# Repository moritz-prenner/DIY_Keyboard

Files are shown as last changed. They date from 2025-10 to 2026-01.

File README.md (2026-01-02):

# DIY_Keyboard 

This project is a full size Keyboard powered by a rp2040 pro micro and a custom pcb designed by myself :)
After I am going to build it it should (hopefully) function like a regular storebought keyboard. It even contains a knob to control volume for example.
I built this project to get better at pcb design and learn something new about keyboard firmware.

Note for the reviewer:

As you probably already seen, my total (in the bom) is around 95$. But this number is without the filament cost for the printing of the case. 
Even tho I am probably going to spend my tickets I am going to earn with this project on filament, I still estimated the cost and added it to the bom total.
That makes my funding request (around 120 - 130 $) - of course I am going to return the rest if it is cheaper than expected.


image (1)
image (2)


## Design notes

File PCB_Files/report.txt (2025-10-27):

Warning: Width correction constrained.  The width correction value must be in the range of [0.000001 mm; 0.199999 mm] for the current design rules.
Plotted to 'D:\DIY_Keyboard\DIY_Keyboard-F_Cu.pdf'.
Plotted to 'D:\DIY_Keyboard\DIY_Keyboard-B_Cu.pdf'.
Plotted to 'D:\DIY_Keyboard\DIY_Keyboard-F_Paste.pdf'.
Plotted to 'D:\DIY_Keyboard\DIY_Keyboard-B_Paste.pdf'.
Plotted to 'D:\DIY_Keyboard\DIY_Keyboard-F_Silkscreen.pdf'.
Plotted to 'D:\DIY_Keyboard\DIY_Keyboard-B_Silkscreen.pdf'.
Plotted to 'D:\DIY_Keyboard\DIY_Keyboard-F_Mask.pdf'.
Plotted to 'D:\DIY_Keyboard\DIY_Keyboard-B_Mask.pdf'.
Plotted to 'D:\DIY_Keyboard\DIY_Keyboard-Edge_Cuts.pdf'.
Info: Done.
Info: Done.

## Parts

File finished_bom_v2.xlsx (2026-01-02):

BOM DIY Keyboard
number | name | price | shipping | customs | total | store | link | payed by
1 | pcb | $24.70 | $18.69 | $8.68 | $52.07 | JLCPCB | https://jlcpcb.com/ | Hackclub
2 | case part 1 | printing legion* |  |  |  |  |  | Hackclub
3 | case part 2 | printing legion* |  |  |  |  |  | Hackclub
4 | oled screen | $0.00 | $0.00 | $0.00 | $0.00 | none | none | myself
5 | microcontroller | $4.12 | $0.00 | - | $4.12 | Alieexpress | link (https://www.aliexpress.us/item/3256806413079215.html) | Hackclub
6 | switches | $14.40 | $0.00 | - | $14.40 | Alieexpress | link (https://www.aliexpress.us/item/3256807287812473.html?curPageLogUid=IzEzjf9NA2AT) | Hackclub
7 | screws | $12.32 | $0.00 | - | $12.32 | Alieexpress | link (https://www.aliexpress.us/item/3256807092650644.html?curPageLogUid=jpGcRnpkoJSX) | Hackclub
8 | threaded inserts | $4.19 | $0.00 | - | $4.19 | Alieexpress | link (https://www.aliexpress.us/item/3256803951626702.html?curPageLogUid=LZ68UpslQYpl) | Hackclub
9 | diodes | $2.97 | - | - | $2.97 | Alieexpress | link (https://www.aliexpress.us/item/3256806974248533.html?curPageLogUid=eBpdBSmcdIFc) | Hackclub
10 | rotary encoder | $1.52 | - | - | $1.52 | Alieexpress | link (https://www.aliexpress.us/item/3256807457768762.html?curPageLogUid=V7HCYoGuFoAu) | Hackclub
11 | keycaps | $4.88 | - | - | $4.88 | Alieexpress | link (https://www.aliexpress.us/item/3256809711493049.html) | Hackclub
12 | tweezers | $1.52 | $0.00 | - | $1.52 | Alieexpress | link (https://www.aliexpress.us/item/2255800812589859.html?curPageLogUid=6AeCtISjiv0Y) | Hackclub
 |  |  |  | total | $97.99
 | * Disclaimer:
 | Because I am planning to participate in construct
 | I am probably going to print the parts myself.
 | I am not going to count my work for the keyboard case for construct!!!

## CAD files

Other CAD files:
CAD_Files/Keyboard_case_lower_part.dwg
CAD_Files/Keyboard_case_upper_part.dwg

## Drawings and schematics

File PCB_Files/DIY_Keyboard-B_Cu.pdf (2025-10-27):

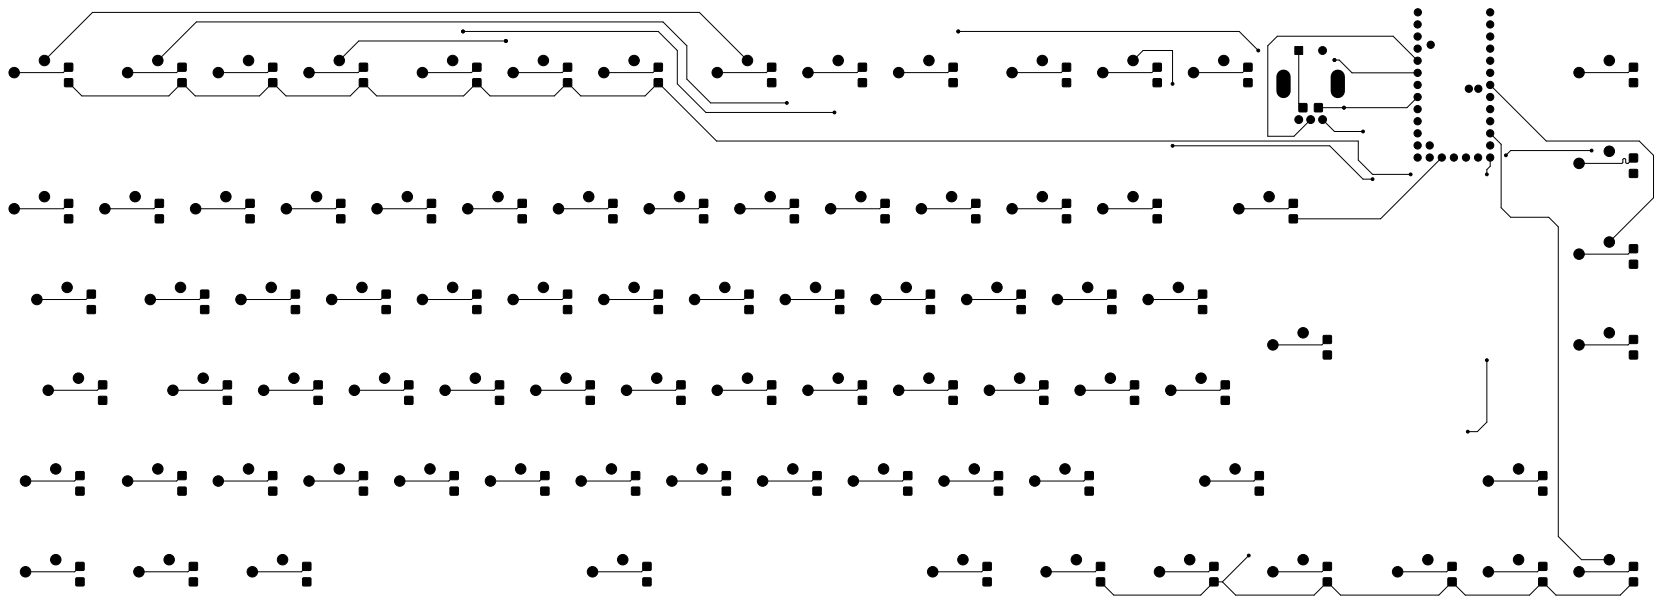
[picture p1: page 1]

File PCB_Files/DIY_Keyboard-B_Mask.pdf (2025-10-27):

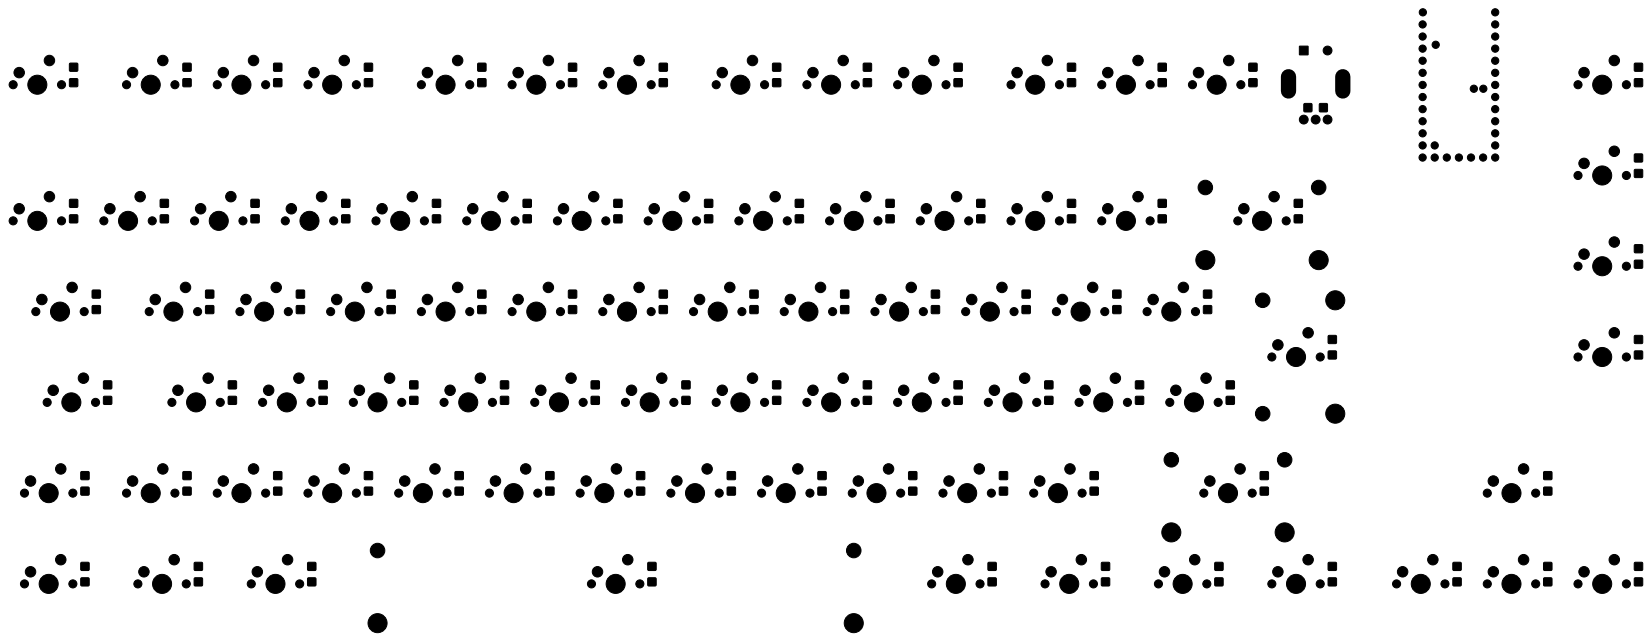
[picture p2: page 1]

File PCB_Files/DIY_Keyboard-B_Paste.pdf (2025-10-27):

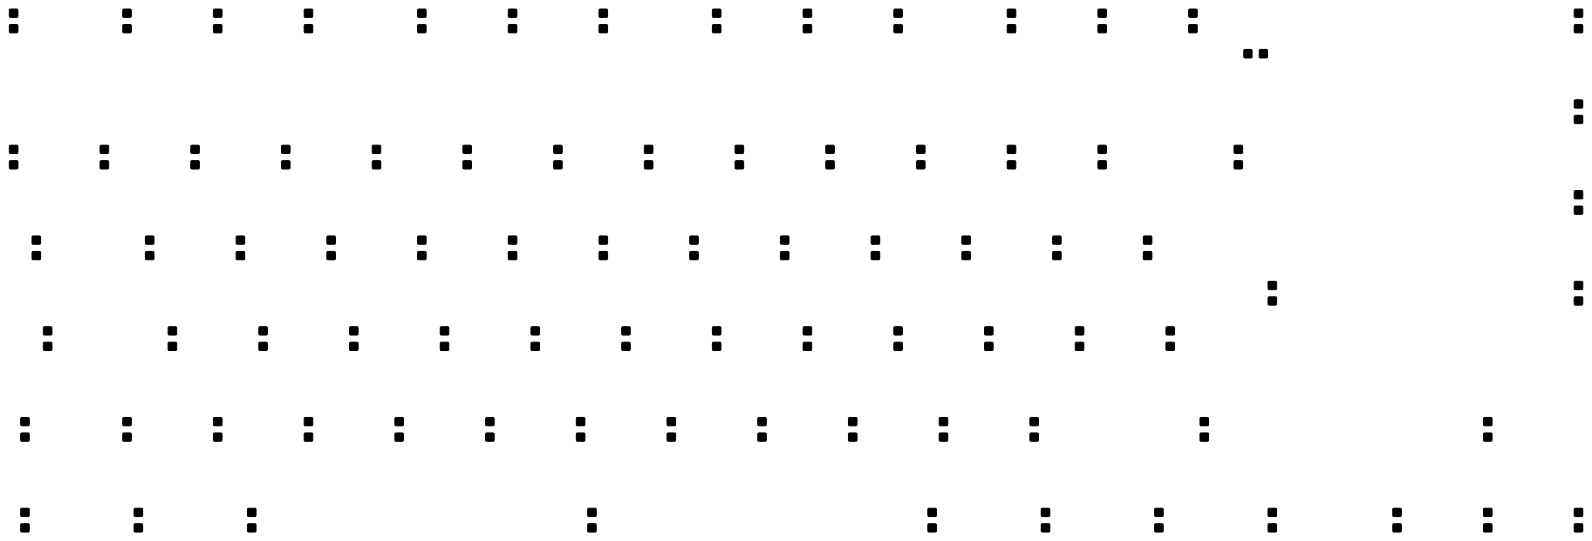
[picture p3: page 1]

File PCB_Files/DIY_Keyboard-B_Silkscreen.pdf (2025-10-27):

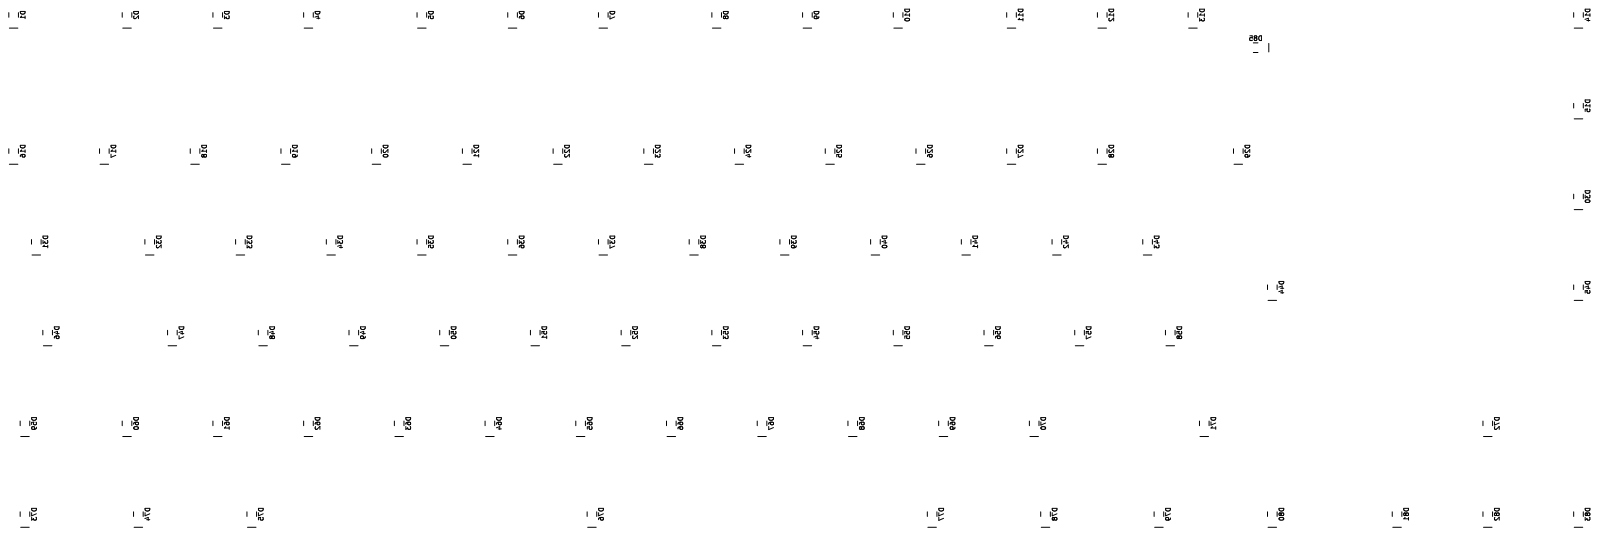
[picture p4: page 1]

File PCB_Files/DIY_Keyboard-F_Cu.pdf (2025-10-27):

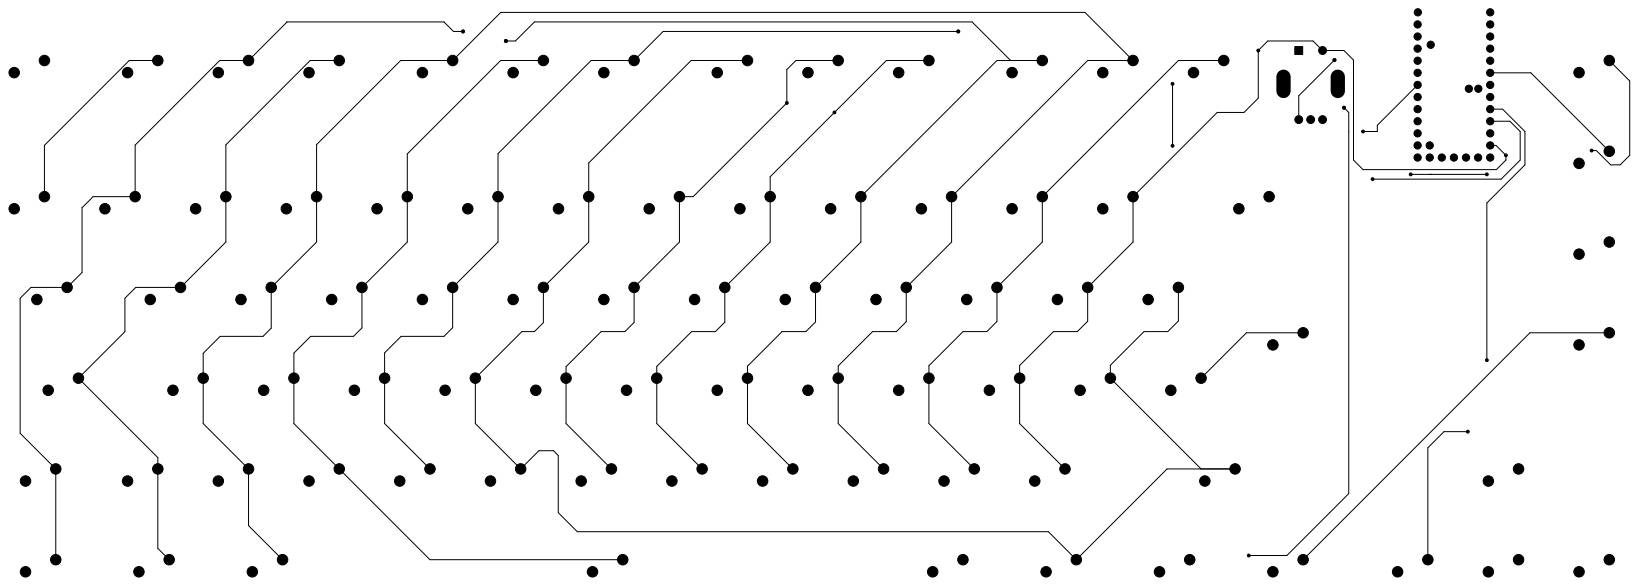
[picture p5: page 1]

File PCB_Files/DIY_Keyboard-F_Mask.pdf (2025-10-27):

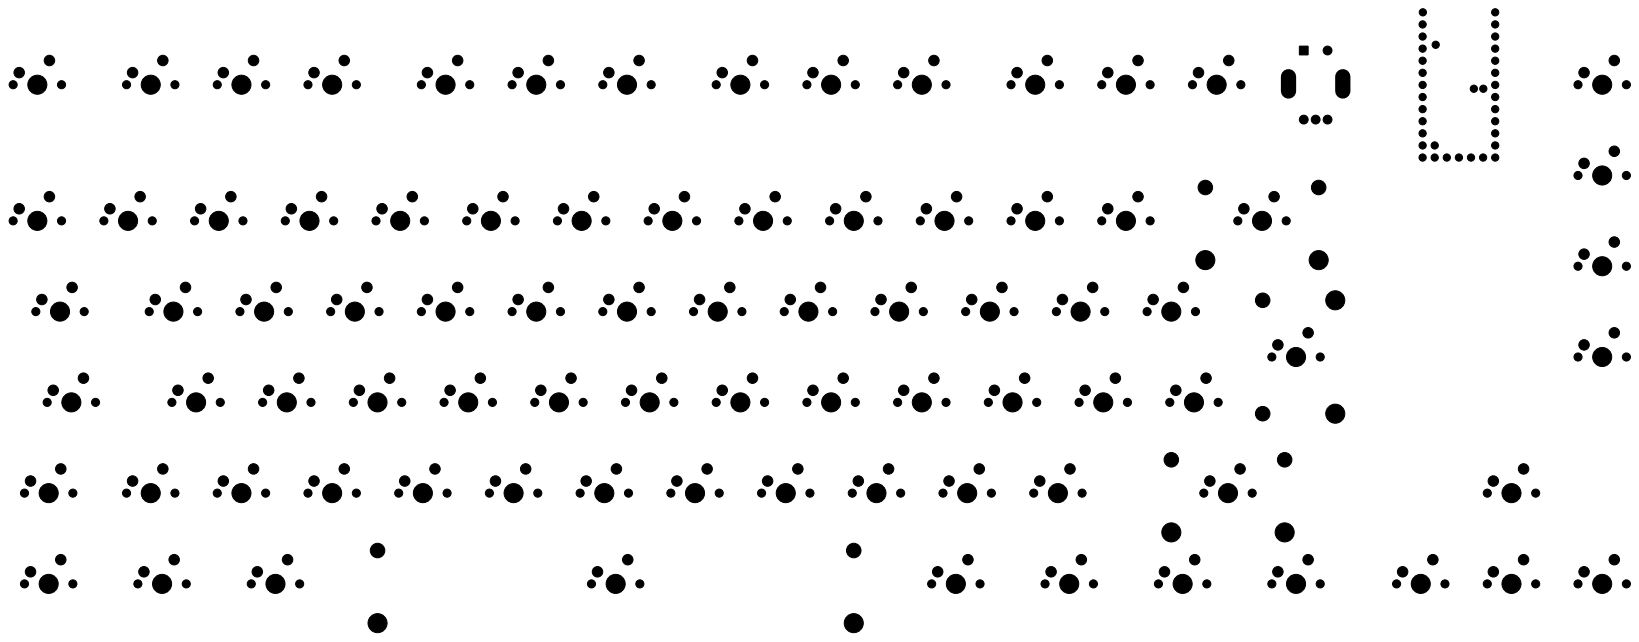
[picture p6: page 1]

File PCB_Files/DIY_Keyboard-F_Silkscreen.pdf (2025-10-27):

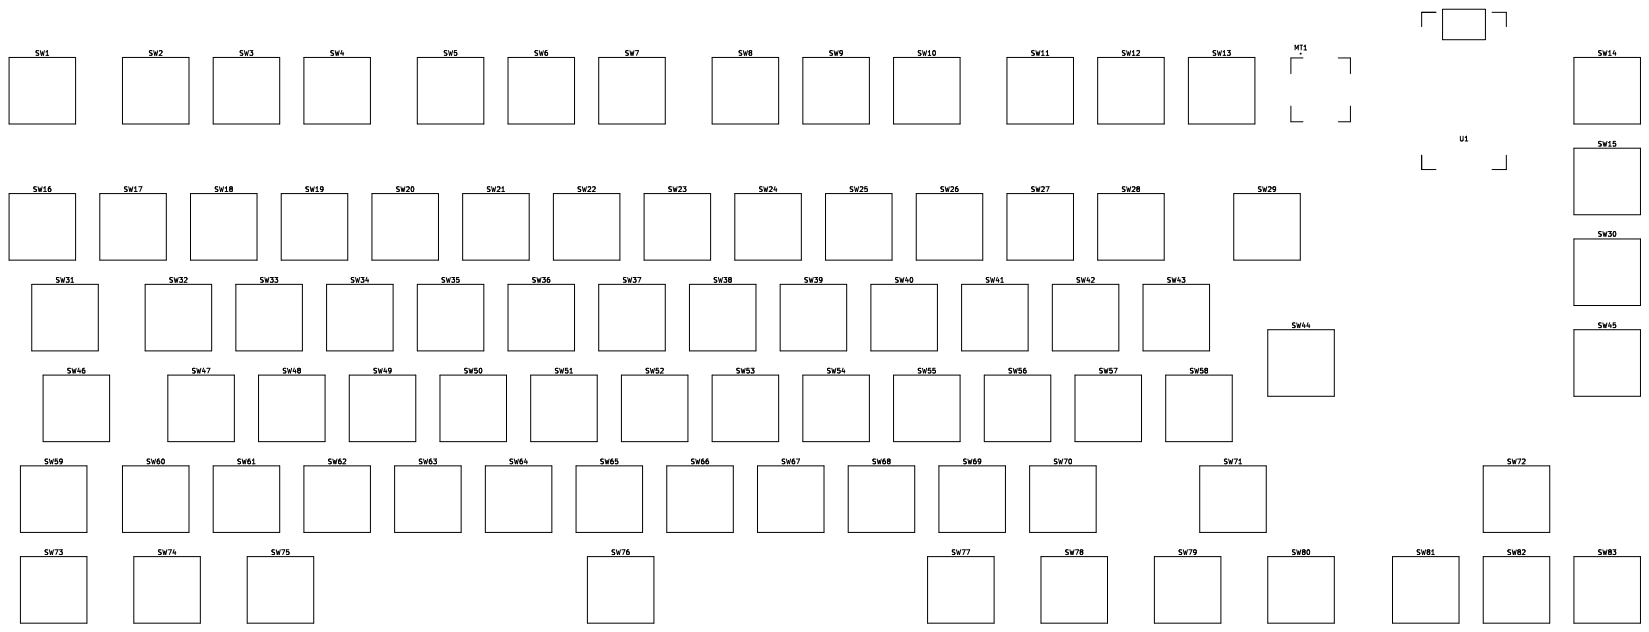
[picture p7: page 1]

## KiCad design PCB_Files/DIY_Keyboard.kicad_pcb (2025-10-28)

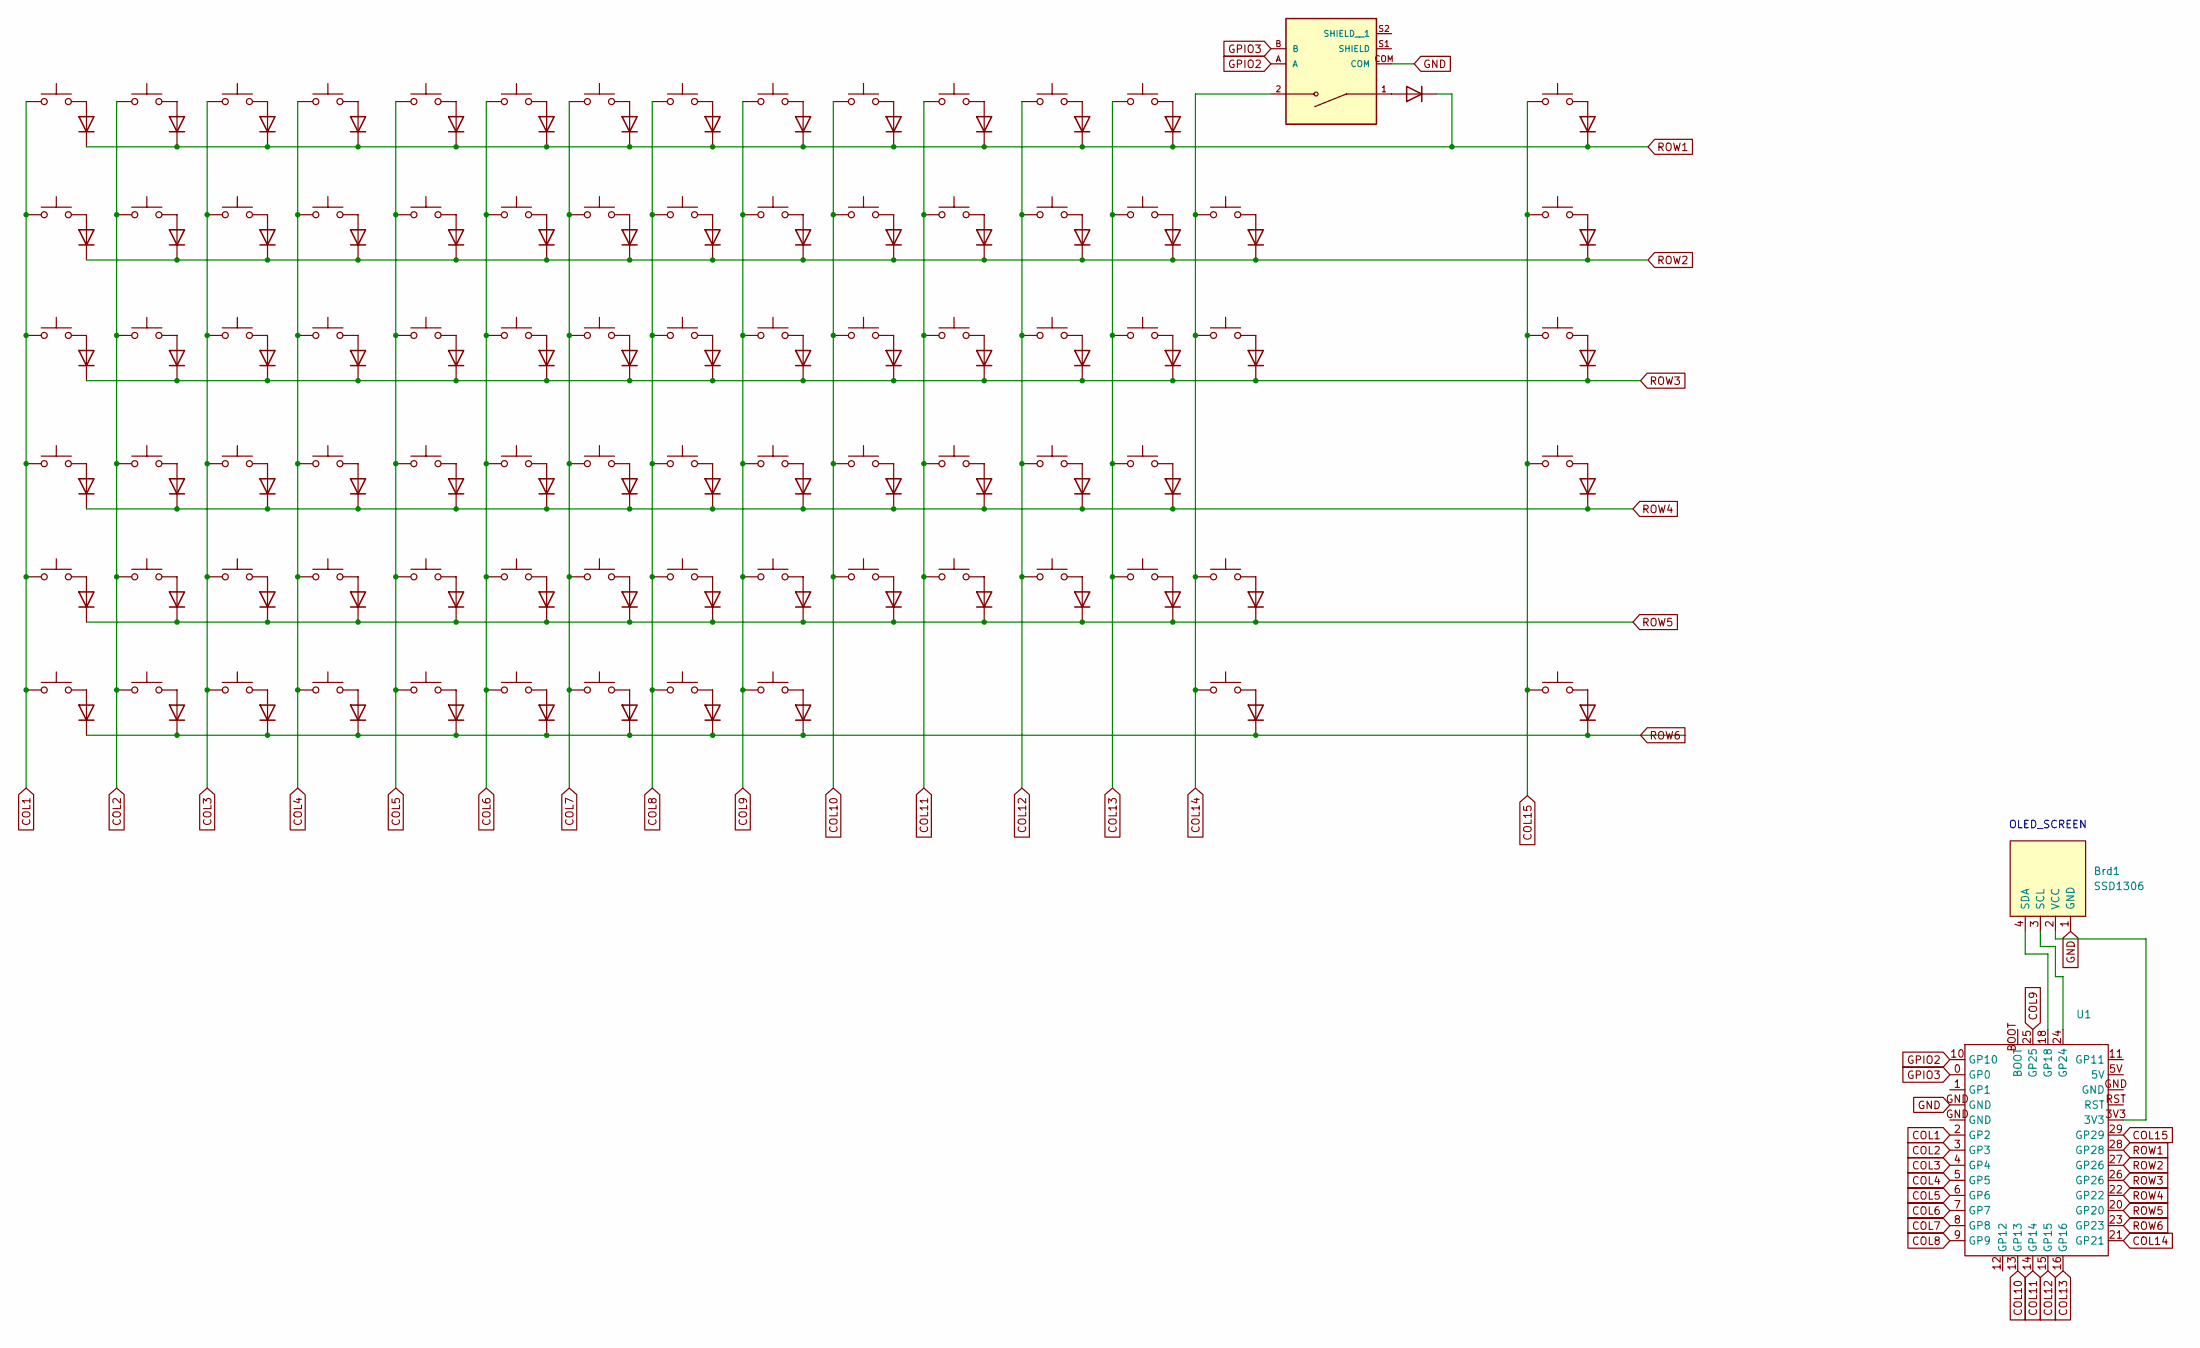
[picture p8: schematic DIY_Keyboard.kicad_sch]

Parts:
Brd1: SSD1306; oled_screen
D1, D2, D3, D4, D5, D6, D7, D8, D9, D10, D11, D12, D13, D14, D15, D16, D17, D18, D19, D20, D21, D22, D23, D24, D25, D26, D27, D28, D29, D30, D31, D32, D33, D34, D35, D36, D37, D38, D39, D40, D41, D42, D43, D44, D45, D46, D47, D48, D49, D50, D51, D52, D53, D54, D55, D56, D57, D58, D59, D60, D61, D62, D63, D64, D65, D66, D67, D68, D69, D70, D71, D72, D73, D74, D75, D76, D77, D78, D79, D80, D81, D82, D83, D85: 1N4148; Crystal_SMD_G8-2Pin_3.2x1.5mm_HandSoldering
MT1: PEC11R-4215F-S0024; XDCR_PEC11R-4215F-S0024; PARTREV Rev. 09/19
SW1, SW2, SW3, SW4, SW5, SW6, SW7, SW8, SW9, SW10, SW11, SW12, SW13, SW14, SW15, SW16, SW17, SW18, SW19, SW20, SW21, SW22, SW23, SW24, SW25, SW26, SW27, SW28, SW30, SW32, SW33, SW34, SW35, SW36, SW37, SW38, SW39, SW40, SW41, SW42, SW43, SW45, SW47, SW48, SW49, SW50, SW51, SW52, SW53, SW54, SW55, SW56, SW57, SW58, SW60, SW61, SW62, SW63, SW64, SW65, SW66, SW67, SW68, SW69, SW70, SW72, SW81, SW82, SW83: SW_Push; SW_Cherry_MX_1.00u_PCB
SW29: SW_Push; SW_Cherry_MX_2.00u_PCB
SW31: SW_Push; SW_Cherry_MX_1.50u_PCB
SW44: SW_Push; SW_Cherry_MX_ISOEnter_PCB_v2
SW46: SW_Push; SW_Cherry_MX_1.75u_PCB
SW59, SW73, SW74, SW75, SW77, SW78, SW79, SW80: SW_Push; SW_Cherry_MX_1.25u_PCB
SW71: SW_Push; SW_Cherry_MX_2.75u_PCB
SW76: SW_Push; SW_Cherry_MX_6.25u_PCB
U1: pro_micro_rp2040

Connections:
COL1: SW1.1, SW16.1, SW31.1, SW46.1, SW59.1, SW73.1, U1.2 (GP2)
COL2: SW2.1, SW17.1, SW32.1, SW47.1, SW60.1, SW74.1, U1.3 (GP3)
COL3: SW3.1, SW18.1, SW33.1, SW48.1, SW61.1, SW75.1, U1.4 (GP4)
COL4: SW4.1, SW19.1, SW34.1, SW49.1, SW62.1, SW76.1, U1.5 (GP5)
COL5: SW5.1, SW20.1, SW35.1, SW50.1, SW63.1, SW77.1, U1.6 (GP6)
COL6: SW6.1, SW21.1, SW36.1, SW51.1, SW64.1, SW78.1, U1.7 (GP7)
COL7: SW7.1, SW22.1, SW37.1, SW52.1, SW65.1, SW79.1, U1.8 (GP8)
COL8: SW8.1, SW23.1, SW38.1, SW53.1, SW66.1, SW80.1, U1.9 (GP9)
COL9: SW9.1, SW24.1, SW39.1, SW54.1, SW67.1, SW81.1, U1.25 (GP25)
COL10: SW10.1, SW25.1, SW40.1, SW55.1, SW68.1, U1.13 (GP13)
COL11: SW11.1, SW26.1, SW41.1, SW56.1, SW69.1, U1.14 (GP14)
COL12: SW12.1, SW27.1, SW42.1, SW57.1, SW70.1, U1.15 (GP15)
COL13: SW13.1, SW28.1, SW43.1, SW58.1, SW71.1, U1.16 (GP16)
COL14: MT1.2, SW29.1, SW44.1, SW72.1, SW82.1, U1.21 (GP21)
COL15: SW14.1, SW15.1, SW30.1, SW45.1, SW83.1, U1.29 (GP29)
GND: Brd1.1 (GND), MT1.COM, U1.GND
GPIO2: MT1.A, U1.10 (GP10)
GPIO3: MT1.B, U1.0 (GP0)
unnamed: Brd1.3 (SCL), U1.24 (GP24)
unnamed: Brd1.4 (SDA), U1.18 (GP18)
unnamed: Brd1.2 (VCC), U1.3V3
unnamed: D1.2 (A), SW1.2
unnamed: D2.2 (A), SW2.2
unnamed: D3.2 (A), SW3.2
unnamed: D4.2 (A), SW4.2
unnamed: D5.2 (A), SW5.2
unnamed: D6.2 (A), SW6.2
unnamed: D7.2 (A), SW7.2
unnamed: D8.2 (A), SW8.2
unnamed: D9.2 (A), SW9.2
unnamed: D10.2 (A), SW10.2
unnamed: D11.2 (A), SW11.2
unnamed: D12.2 (A), SW12.2
unnamed: D13.2 (A), SW13.2
unnamed: D14.2 (A), SW14.2
unnamed: D15.2 (A), SW15.2
unnamed: D16.2 (A), SW16.2
unnamed: D17.2 (A), SW17.2
unnamed: D18.2 (A), SW18.2
unnamed: D19.2 (A), SW19.2
unnamed: D20.2 (A), SW20.2
unnamed: D21.2 (A), SW21.2
unnamed: D22.2 (A), SW22.2
unnamed: D23.2 (A), SW23.2
unnamed: D24.2 (A), SW24.2
unnamed: D25.2 (A), SW25.2
unnamed: D26.2 (A), SW26.2
unnamed: D27.2 (A), SW27.2
unnamed: D28.2 (A), SW28.2
unnamed: D29.2 (A), SW29.2
unnamed: D30.2 (A), SW30.2
unnamed: D31.2 (A), SW31.2
unnamed: D32.2 (A), SW32.2
unnamed: D33.2 (A), SW33.2
unnamed: D34.2 (A), SW34.2
unnamed: D35.2 (A), SW35.2
unnamed: D36.2 (A), SW36.2
unnamed: D37.2 (A), SW37.2
unnamed: D38.2 (A), SW38.2
unnamed: D39.2 (A), SW39.2
unnamed: D40.2 (A), SW40.2
unnamed: D41.2 (A), SW41.2
unnamed: D42.2 (A), SW42.2
unnamed: D43.2 (A), SW43.2
unnamed: D44.2 (A), SW44.2
unnamed: D45.2 (A), SW45.2
unnamed: D46.2 (A), SW46.2
unnamed: D47.2 (A), SW47.2
unnamed: D48.2 (A), SW48.2
unnamed: D49.2 (A), SW49.2
unnamed: D50.2 (A), SW50.2
unnamed: D51.2 (A), SW51.2
unnamed: D52.2 (A), SW52.2
unnamed: D53.2 (A), SW53.2
unnamed: D54.2 (A), SW54.2
unnamed: D55.2 (A), SW55.2
unnamed: D56.2 (A), SW56.2
unnamed: D57.2 (A), SW57.2
unnamed: D58.2 (A), SW58.2
unnamed: D59.2 (A), SW59.2
unnamed: D60.2 (A), SW60.2
unnamed: D61.2 (A), SW61.2
unnamed: D62.2 (A), SW62.2
unnamed: D63.2 (A), SW63.2
unnamed: D64.2 (A), SW64.2
unnamed: D65.2 (A), SW65.2
unnamed: D66.2 (A), SW66.2
unnamed: D67.2 (A), SW67.2
unnamed: D68.2 (A), SW68.2
unnamed: D69.2 (A), SW69.2
unnamed: D70.2 (A), SW70.2
unnamed: D71.2 (A), SW71.2
unnamed: D72.2 (A), SW72.2
unnamed: D73.2 (A), SW73.2
unnamed: D74.2 (A), SW74.2
unnamed: D75.2 (A), SW75.2
unnamed: D76.2 (A), SW76.2
unnamed: D77.2 (A), SW77.2
unnamed: D78.2 (A), SW78.2
unnamed: D79.2 (A), SW79.2
unnamed: D80.2 (A), SW80.2
unnamed: D81.2 (A), SW81.2
unnamed: D82.2 (A), SW82.2
unnamed: D83.2 (A), SW83.2
unnamed: D85.2 (A), MT1.1
ROW1: D1.1 (K), D2.1 (K), D3.1 (K), D4.1 (K), D5.1 (K), D6.1 (K), D7.1 (K), D8.1 (K), D9.1 (K), D10.1 (K), D11.1 (K), D12.1 (K), D13.1 (K), D14.1 (K), D85.1 (K), U1.28 (GP28)
ROW2: D15.1 (K), D16.1 (K), D17.1 (K), D18.1 (K), D19.1 (K), D20.1 (K), D21.1 (K), D22.1 (K), D23.1 (K), D24.1 (K), D25.1 (K), D26.1 (K), D27.1 (K), D28.1 (K), D29.1 (K), U1.27 (GP26)
ROW3: D30.1 (K), D31.1 (K), D32.1 (K), D33.1 (K), D34.1 (K), D35.1 (K), D36.1 (K), D37.1 (K), D38.1 (K), D39.1 (K), D40.1 (K), D41.1 (K), D42.1 (K), D43.1 (K), D44.1 (K), U1.26 (GP26)
ROW4: D45.1 (K), D46.1 (K), D47.1 (K), D48.1 (K), D49.1 (K), D50.1 (K), D51.1 (K), D52.1 (K), D53.1 (K), D54.1 (K), D55.1 (K), D56.1 (K), D57.1 (K), D58.1 (K), U1.22 (GP22)
ROW5: D59.1 (K), D60.1 (K), D61.1 (K), D62.1 (K), D63.1 (K), D64.1 (K), D65.1 (K), D66.1 (K), D67.1 (K), D68.1 (K), D69.1 (K), D70.1 (K), D71.1 (K), D72.1 (K), U1.20 (GP20)
ROW6: D73.1 (K), D74.1 (K), D75.1 (K), D76.1 (K), D77.1 (K), D78.1 (K), D79.1 (K), D80.1 (K), D81.1 (K), D82.1 (K), D83.1 (K), U1.23 (GP23)

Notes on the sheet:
OLED_SCREEN

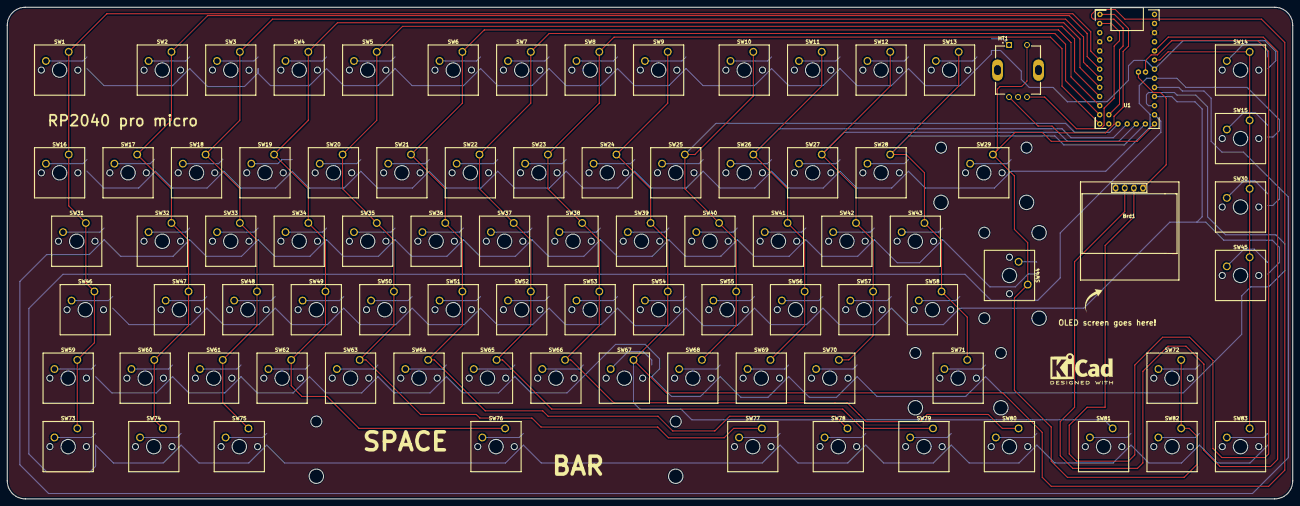
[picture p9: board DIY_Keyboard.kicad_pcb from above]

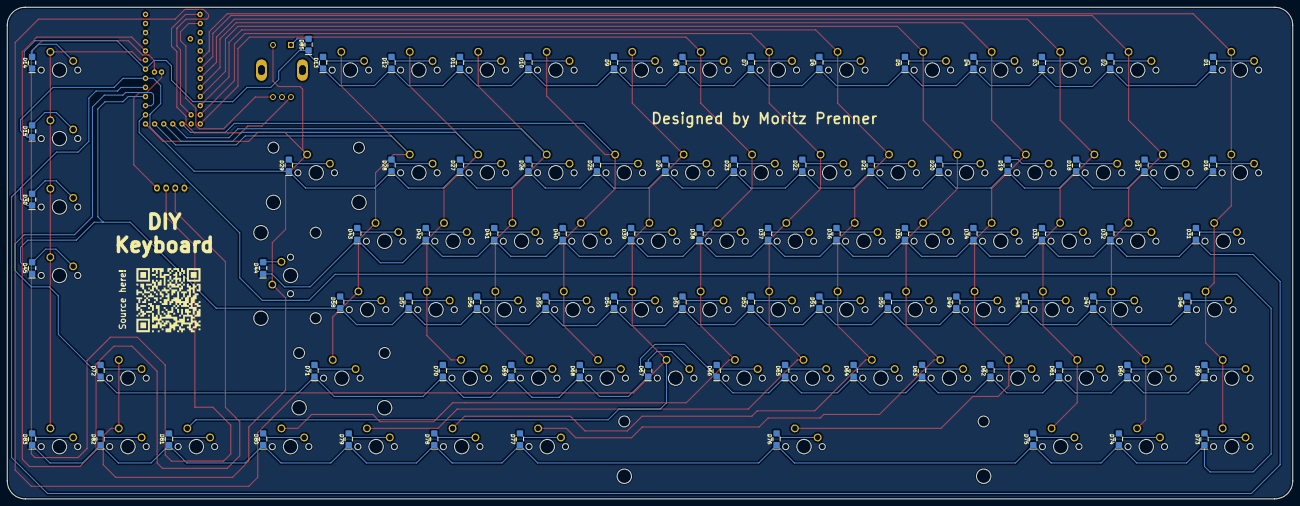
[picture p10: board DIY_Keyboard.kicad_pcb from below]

Board: 2 copper layers, 357.7 x 136.8 mm, 170 parts (84 on the bottom side), 111 nets.

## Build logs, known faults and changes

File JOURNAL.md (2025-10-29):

<!--
  ===================    !!READ THIS NOTICE!!   ====================
  DO NOT edit this file manually. Your changes WILL BE OVERWRITTEN!
  This journal is auto generated and updated by Hack Club Blueprint.
  To edit this file, please edit your journal entries on Blueprint.
  ==================================================================
-->

## 10/4/2025 - I created the layout i am going to use.  


I want to use a ISO - Layout (German) and I want one number row and one Shortcut row. Also a volume knob is important for me. I also decided on some shortcut keys on the right hand side which i am going to bind on discord mute and some other useful functions.  

## 10/5/2025 - New Layout and schematic  



I rearranged the layout and made the schematic. I settled on the rp2040 based RP2040 Pro Micro 16MB/128Mbit USB-C Controller from Keeb.io. I am going to use 84 switches (12 rows, 7 columns). And I am going to implement a rotary encoder (PEC11R-4215F-S0024). And I am probaply going to include a acrylic glass window in the case which I am going to start working on next.  

## 10/12/2025 - I updated the schematic.  



I used labels. I used a new symbol for the microcontroller. I updated the matrix. I assigned footprints and decided on diodes I am going to use. I am going to use smd diodes. Hopefully blueprint will add helping hands or some sort of smd soldering accesories to the toobag.

## 10/26/2025 - Routed the PCB  

I updated the schematic to make wiring easier. Then I layed out all of the components and added an OLED screen. Then I routed everything and exported some pictures.

## 10/27/2025 - I updated the pcb.  

I fixed most of the errors in the DRC. I changed the footprint of the oled screen. And I also improved my ground plane. I think I am now going to move on to the case. 

## 10/28/2025 - Finalized the pcb  

I finalized the pcb design with changes like:
- rotary encoder better aligned
- enter key rotated by 90 degrees
- etc
You can view my design on my
Github: https://github.com/moritz-prenner/DIY_Keyboard
or via kicanvas: https://kicanvas.org/?github=https%3A%2F%2Fgithub.com%2Fmoritz-prenner%2FDIY_Keyboard

## 10/29/2025 - Started the case and plate design  

I started the plate and case design. I am going to use a top mount. I am currently trying to lay every component out and check the clearance. (e.g pcb, switches)

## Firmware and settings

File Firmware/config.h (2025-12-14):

#pragma once

#define MATRIX_ROWS 5
#define MATRIX_COLS 15

#define MATRIX_ROW_PINS {GP2, GP3, GP4, GP5, GP6}
#define MATRIX_COL_PINS {GP7, GP8, GP9, GP10, GP11, GP12, GP13, GP14, GP15, GP16, GP17, GP18, GP19, GP20, GP21}

#define DIODE_DIRECTION COL2ROW

#define ENCODERS_PAD_A {GP26}
#define ENCODERS_PAD_B {GP27}

#define USB_VBUS_PIN GP24

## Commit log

2025-10-04 Create BOM
2025-10-04 Update BOM
2025-12-17 commit 2
    [DIY_Keyboard.kicad_sch]
